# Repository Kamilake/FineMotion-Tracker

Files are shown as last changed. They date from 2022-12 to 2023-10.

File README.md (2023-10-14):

FineMotionLogo8bit

# SlimeVR Based Full-Body Tracker

```
혹시 트래커를 어디선가 구해서 QR코드를 스캔해 여기에 왔고 구매자가 아무것도 알려주지 않았다면 디스코드 kamilake 로 디엠주세요!
```

ESP8266 Motion Capture Devices for SlimeVR Ecosystem

Thinnest SlimeVR Tracker!

Full SMT PCB operating in MPU-6500 6DoF mode

Operate with all 5V chargers, including C to C PD chargers.

You can use it simply by ordering it from the fabricator


<!--![FBT_Round_2022-Feb-21_12-32-22AM-000_CustomizedView14755583882_png - 복사본](https://user-images.githubusercontent.com/15166740/161261406-e853b4be-313f-4721-82e6-cb6b48a9e55c.png)
![KakaoTalk_20220223_222725417_01](https://user-images.githubusercontent.com/15166740/161364606-c8e09892-575d-4725-931e-a6b7f6b5f61f.jpg)
![KakaoTalk_20220223_222725417](https://user-images.githubusercontent.com/15166740/161364617-89621510-34f0-4919-be8a-b33350d9140c.jpg)
![image](https://user-images.githubusercontent.com/15166740/161454675-0740d4ca-4264-4b6e-8f56-9f29aa31817a.png)
![image](https://user-images.githubusercontent.com/15166740/161454916-a54c4693-e9c1-454c-85dc-dd0a7822720e.png)
![KakaoTalk_20220420_084354356_01](https://user-images.githubusercontent.com/15166740/164119670-261c3e02-e0fe-4508-9886-2ccc19d5d1fd.jpg)
![KakaoTalk_20220726_093847052](https://user-images.githubusercontent.com/15166740/180898132-acec5d8d-918e-4d9e-ad32-58ac35cc4740.png)-->




KakaoTalk_20221224_130624400_03
KakaoTalk_20221224_130624400_07

## Why should that tracker be able to be detached from the strap?

It is because of the start-up calibration of the MPU-6000 series.

When the MPU first powers up, the DMP measures the static noise, but this needs to be done on every boot. In other words, to reboot the tracker in-game, you must detach it from your body. Not only does this strap adapter help make it very convenient, but it is also a great help in tracker maintenance!

It only takes 10 seconds for you to assemble the tracker sensor and adapter, and less than 30 seconds to assemble all the trackers to your body \:P

It is eco-friendly to save the life of Velcro straps and easily replace broken adapters.

## Specification

- Power Rating: 500mA@5V (TProg: 2.4KOhm)
- Wi-Fi: 802.11bgn 2.4GHz (20.5mW@2dBi)
- Protection Circuit: Depend on battery
- IMU: Invensense MPU-6500 6DoF Attitude detection sensor
- The radio wave safety of this product has been verified by a nationally recognized testing agency.

## Prerequirements

- PCB: [This Repo!](/PCBs)
- 3D Model: [This Repo!](/3D%20Models)
- Belt Strap: https://aliexpress.com/item/1005003002833146.html, or any 50mm width Strap
- Battery: https://aliexpress.com/item/1005004165245143.html, or any 702050 Cell
- USB Cable: https://aliexpress.com/item/1005004409330904.html, or any Type-C cables

## How do I make it?

1. [Order PCB!](/PCBs)
2. Order Belt, Battery!
3. [Print Shell!](/3D%20Models)
4. Go to SteamVR...

## defines.h
```cpp
#define FineMotion_v5
#define IMU IMU_MPU6500
#define IMU_ROTATION DEG_0
#define BOARD BOARD_NODEMCU
#define SECOND_IMU IMU
#define SECOND_IMU_ROTATION IMU_ROTATION
#define BATTERY_MONITOR 1
#define BATTERY_SHIELD_RESISTANCE 0
#define BATTERY_SHIELD_R1 12
#define BATTERY_SHIELD_R2 47
#define PIN_IMU_SDA 4
#define PIN_IMU_SCL 5
#define PIN_IMU_INT 0xFF
#define PIN_IMU_INT_2 0xFF
#define PIN_BATTERY_LEVEL 17
```

## Why do trackers have to be thin?





The thinner the tracker, the closer the IMU is to the bone and the better the tracking accuracy. It is less affected by inertial force in fast movements.. Above all, it is comfortable when lying on the bed facing the tracker!

## License
**This hardware is licensed under the CERN-OHL-P v2 license**, which is a permissive,
non-viral and non-reciprocal open hardware license. Unlike software licenses like
MIT and Apache 2.0, it better handles the nuances of hardware and protects both
the licensor and licensee from patent lawsuits.

**Unless you explicitly state otherwise, any contribution intentionally submitted
for inclusion in this work by you, shall be licensed as above, without any
additional terms or conditions.**

### Conveying notice of License
Note that as part of the CERN-OHL-P v2 license, recipients of manufactured
hardware must also receive notice of the above license. One such
method of conveying the notice is to include a link to the original source repo,
or printing "Licensed under CERN-OHL-P v2" on the PCB silkscreen. For more info,
see [here](https://ohwr.org/project/cernohl/wikis/Documents/CERN-OHL-version-2).

This is conceptually similar to the MIT/Apache 2.0 Licenses, where the original
license must still be included as a notice even when the source is modified and
subsequently relicensed under different terms.

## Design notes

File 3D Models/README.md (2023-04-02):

# File List

- FineMotion Tracker v172.f3z

  Fusion 360 archive file for who want to edit this model

- FineMotion Tracker v172.step

  STEP file for who want to import this model to other software

- FineMotion Tracker v172.usdc

  USD file for who want to import this model to other software

- FineMotion Tracker v172_AUX Sensor_1_AUX Cover.3mf

  3MF file for 3D printing
  
  Wired External Sensor Cover (Duplicate of Main Sensor Cover)

- FineMotion Tracker v172_AUX Sensor_1_AUX Shell.3mf

  3MF file for 3D printing
  
  Wired External Sensor Shell (Duplicate of Main Sensor Shell)

- FineMotion Tracker v172_AUX Sensor_1_FineMotion AUX Sensor PCB.3mf

  3MF file for Rendering (Do not print)
  
  Wired External Sensor PCB

- FineMotion Tracker v172_Curved Strap Mount with Supporter_1_Curved Strap Mount with Supporter.3mf

  3MF file for 3D printing
  
  Curved Strap Mount with Supporter (Vertical Printing) (Recommended)

- FineMotion Tracker v172_Curved Strap Mount_1_Curved Strap Mount.3mf

  3MF file for 3D printing
  
  Curved Strap Mount

- FineMotion Tracker v172_FineMotion_1_BNO085 Cover_1_BNO085 Cover.3mf

  3MF file for 3D printing
  
  Adafruit BNO085 Sensor Cover for Main Sensor (Usually not needed)

- FineMotion Tracker v172_FineMotion_1_Battery_1_Battery.3mf

  3MF file for Rendering (Do not print)
  
  702050 Lipo Battery 3D Model

- FineMotion Tracker v172_FineMotion_1_Chassis_1_Chassis.3mf

  3MF file for 3D printing
  
  Main Sensor Chassis (Recommended)

- FineMotion Tracker v172_FineMotion_1_Main Cover_1_Main Cover.3mf

  3MF file for 3D printing
  
  Main Sensor / External Sensor Cover (Recommended)

- FineMotion Tracker v172_FineMotion_1_PCB_1_FineMotion v5a PCB.3mf

  3MF file for Rendering (Do not print)
  
  Main Sensor PCB

- FineMotion Tracker v172_Flat Strap Mount (Easy Charge)_1_Flat Strap Mount (Easy Charge).3mf

  3MF file for 3D printing
  
  Flat Strap Mount (Not recommended)

- FineMotion Tracker v172_Flat Strap Mount_1_Flat Strap Mount.3mf

  3MF file for 3D printing
  
  Flat Strap Mount (Chest/Waist Mount) (Recommended)

## [For F360 user] What is \*.f3z?



As you can see in the screenshot, that's it.

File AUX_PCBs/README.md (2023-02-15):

# Custom assembly using Kikit JLC

Due to JLCPCB's new assembly policy, soldering on the bottom side or using a non-black PCB will incur additional charges.
Bottom side soldering is not possible if the "Economic" assembly option is selected.
As the bottom side soldering is only for the connector, manual assembly is recommended.  
But.. if you ordering more than 31 boards, it is more economical to choose the `Standard assembly` option with panelization.  
If you have any further questions, please feel free to contact me!(Issues, mail, Discord, etc.)  

- You need `KiCad 6.0 Command Prompt` and [Kikit](https://github.com/yaqwsx/KiKit) with KiCad 6

## Panalize and Fabrication

```batch
kikit panelize ^
    -p :jlcTooling ^
    --layout "grid; rows: 7; cols: 3; space: 3mm" ^
    --tabs "fixed; hwidth: 10mm; vwidth: 15mm" ^
    --cuts vcuts ^
    --source "tolerance: 1000mm" ^
    --framing "tightframe; width: 5mm; space: 3mm; " ^
    --post "millradius: 1mm" ^
    "./FineMotion_AUX.kicad_pcb" ^
    "FineMotion_AUX_panel.kicad_pcb"

kikit fab jlcpcb ^
    --assembly ^
    --schematic ./FineMotion_AUX.kicad_sch ^
    --ignore TP1,J1 ^
    "./FineMotion_AUX_panel.kicad_pcb" ^
    "./Gerber/FineMotion_Panel"

```

## Fabrication Only

### Using Default Configuration

```batch
kikit fab jlcpcb ^
    --assembly ^
    --schematic ./FineMotion_AUX.kicad_sch ^
    --ignore TP1,TP2 ^
    --no-drc ^
    "./FineMotion_AUX_panel.kicad_pcb" ^
    "./Gerber/FineMotion"
```

<br><hr><br>

## Panalize and Fabrication Extension Sensor

```batch
```

## Fabrication Extension Sensor Only

### Using Default Configuration

```batch
```

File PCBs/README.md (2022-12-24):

# Custom assembly using Kikit JLC

Due to JLCPCB's new assembly policy, soldering on the bottom side or using a non-black PCB will incur additional charges.   
Bottom side soldering is not possible if the "Economic" assembly option is selected.   
As the bottom side soldering is only for the connector, manual assembly is recommended.  
But.. if you ordering more than 31 boards, it is more economical to choose the `Standard assembly` option with panelization.  
If you have any further questions, please feel free to contact me!(Issues, mail, Discord, etc.)  

- You need `KiCad 6.0 Command Prompt` and [Kikit](https://github.com/yaqwsx/KiKit) with KiCad 6

## Panalize and Fabrication
```batch
kikit panelize ^
    -p :jlcTooling ^
    --layout "grid; rows: 7; cols: 3; space: 3mm" ^
    --tabs "fixed; hwidth: 10mm; vwidth: 15mm" ^
    --cuts vcuts ^
    --source "tolerance: 1000mm" ^
    --post "millradius: 1mm" ^
    "./FineMotion-5.kicad_pcb" ^
    "FineMotion-5_panel.kicad_pcb"

kikit fab jlcpcb ^
    --assembly ^
    --schematic ./FineMotion-5.kicad_sch ^
    --ignore TP1,TP2 ^
    --no-drc ^
    "./FineMotion-5_panel.kicad_pcb" ^
    "./Gerber/FineMotion_Panel"
```

## Fabrication Only

### Using Default Configuration
```batch
kikit fab jlcpcb ^
    --assembly ^
    --schematic ./FineMotion-5.kicad_sch ^
    --ignore TP1,TP2 ^
    --no-drc ^
    "./FineMotion-5_panel.kicad_pcb" ^
    "./Gerber/FineMotion"
```

<br><hr><br>   

## Panalize and Fabrication Extension Sensor
```batch
```

## Fabrication Extension Sensor Only

### Using Default Configuration
```batch
```
<!--
### Using internal MPU-6050+QMC5883L and Left side Lipo
```batch
kikit fab jlcpcb ^
    --assembly ^
    --schematic ./KTracker.kicad_sch ^
    --ignore BT1,J1,J4,J5 ^
    --no-drc ./KTracker.kicad_pcb ^
    "./Gerber/Using internal MPU-6050+QMC5883L and Left side Lipo"
```

### Using GY-521 and bottom Lipo
```batch
kikit fab jlcpcb ^
    --assembly ^
    --schematic ./KTracker.kicad_sch ^
    --ignore U8,U3,R20,R21,C16,C12,C11,R12,R11,BT1,J3,J4,J5 ^
    --no-drc ./KTracker.kicad_pcb ^
    "./Gerber/Using GY-521 and bottom Lipo"

```

### Using GY-521 and 18650
```batch
kikit fab jlcpcb ^
    --assembly ^
    --schematic ./KTracker.kicad_sch ^
    --ignore U8,U3,R20,R21,C16,C12,C11,R12,R11,J1,J3,J4,J5 ^
    --no-drc ./KTracker.kicad_pcb ^
    "./Gerber/Using GY-521 and 18650"

```

kikit fab jlcpcb --assembly --schematic ./FineMotion-5.kicad_sch --ignore TP1,TP2 --no-drc ./FineMotion-5.kicad_pcb "./Gerber/FM6500"

kikit fab jlcpcb --assembly --schematic ./KTracker_AUX.kicad_sch  --ignore A1 --no-drc ./KTracker_AUX.kicad_pcb "./Gerber/FM6500E"

kikit panelize ^
    -p :jlcTooling ^
    --layout "grid; rows: 7; cols: 3; space: 3mm" ^
    --tabs "fixed; hwidth: 10mm; vwidth: 15mm" ^
    --cuts vcuts ^
    --source "tolerance: 1000mm" ^
    --post "millradius: 1mm" ^
    "./FineMotion-5.kicad_pcb" ^
    "FineMotion-5_panel.kicad_pcb"

kikit fab jlcpcb ^
    --assembly ^
    --schematic ./FineMotion-5.kicad_sch ^
    --ignore TP1,TP2 ^
    --no-drc ^
    "./FineMotion-5_panel.kicad_pcb" ^
    "./Gerber/FineMotion_Panel"

---

-->

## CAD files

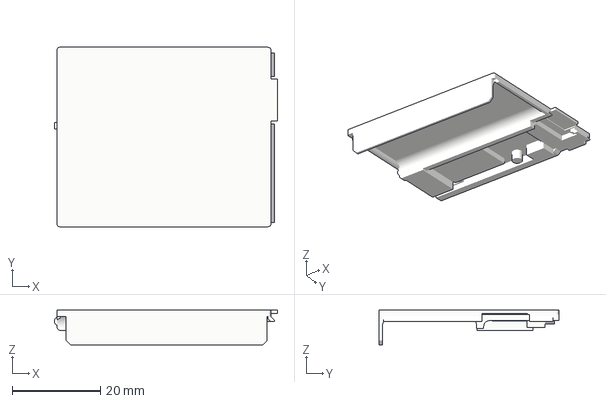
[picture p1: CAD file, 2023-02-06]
3D Models/FineMotion Tracker v172_FineMotion_1_Main Cover_1_Main Cover.3mf
50.4 x 40.6 x 7.90 mm

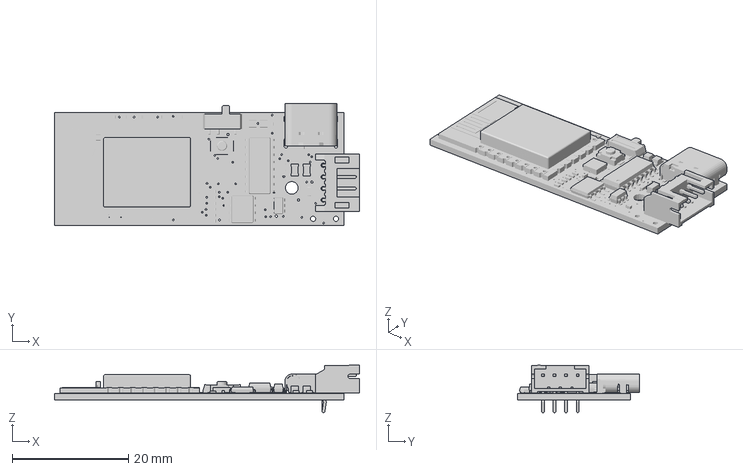
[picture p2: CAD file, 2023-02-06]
3D Models/FineMotion Tracker v172_FineMotion_1_PCB_1_FineMotion v5a PCB.3mf
52.6 x 21.0 x 8.25 mm

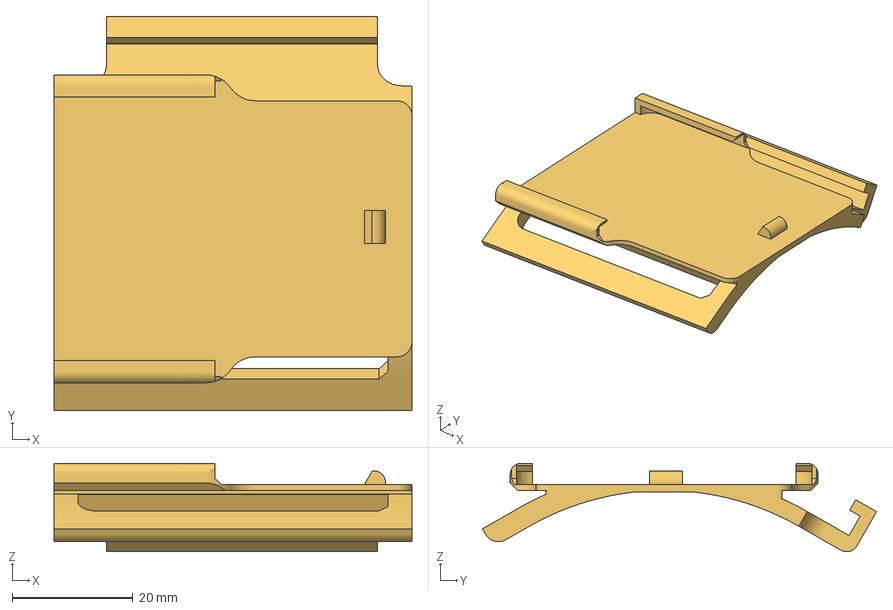
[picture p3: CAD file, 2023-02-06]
3D Models/FineMotion Tracker v172_Curved Strap Mount_1_Curved Strap Mount.3mf
59.4 x 65.4 x 14.7 mm

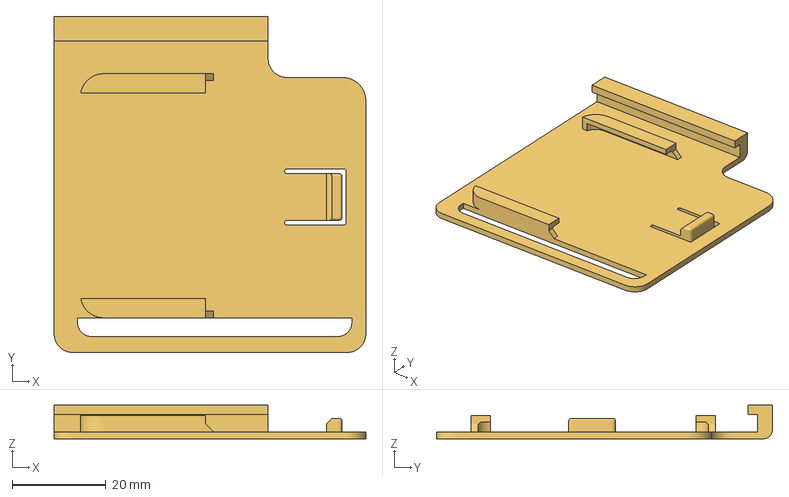
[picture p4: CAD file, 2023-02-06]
3D Models/FineMotion Tracker v172_Flat Strap Mount (Easy Charge)_1_Flat Strap Mount (Easy Charge).3mf
66.5 x 71.7 x 7.20 mm

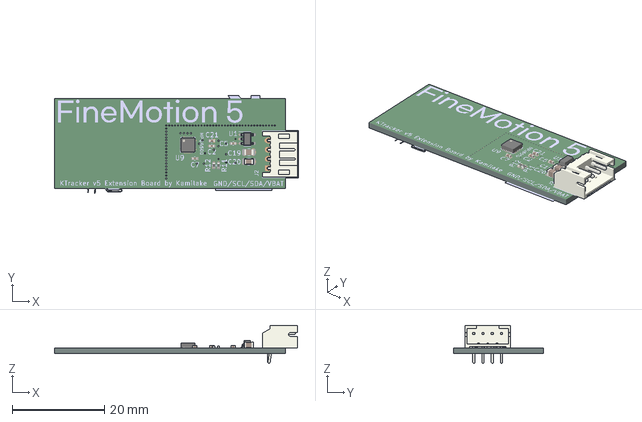
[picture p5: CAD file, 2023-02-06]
3D Models/FineMotion Tracker v172_AUX Sensor_1_FineMotion AUX Sensor PCB.3mf
52.8 x 21.2 x 8.25 mm

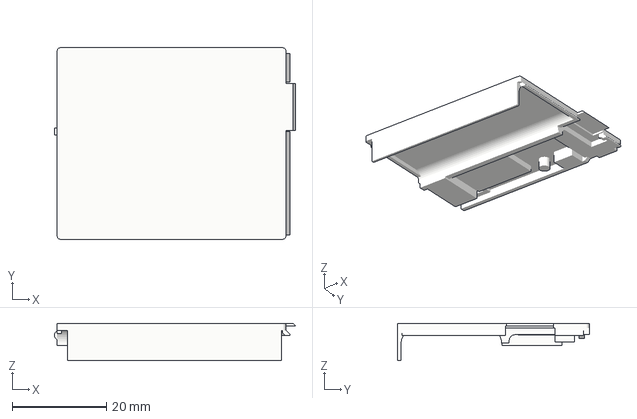
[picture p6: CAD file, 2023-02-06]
3D Models/FineMotion Tracker v172_AUX Sensor_1_AUX Cover.3mf
51.1 x 40.6 x 7.90 mm

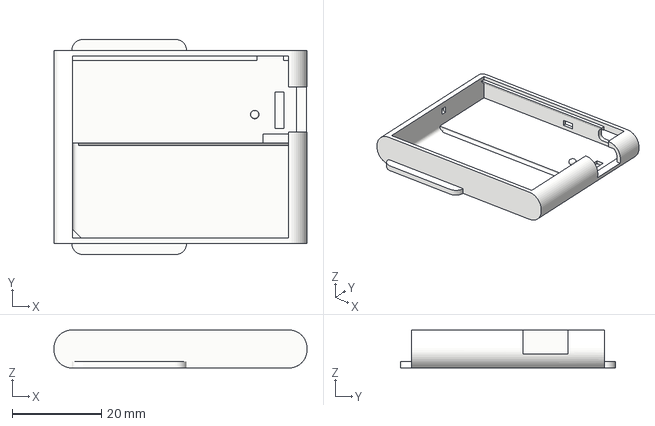
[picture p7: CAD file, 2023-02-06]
3D Models/FineMotion Tracker v172_FineMotion_1_Chassis_1_Chassis.3mf
56.7 x 48.2 x 8.50 mm

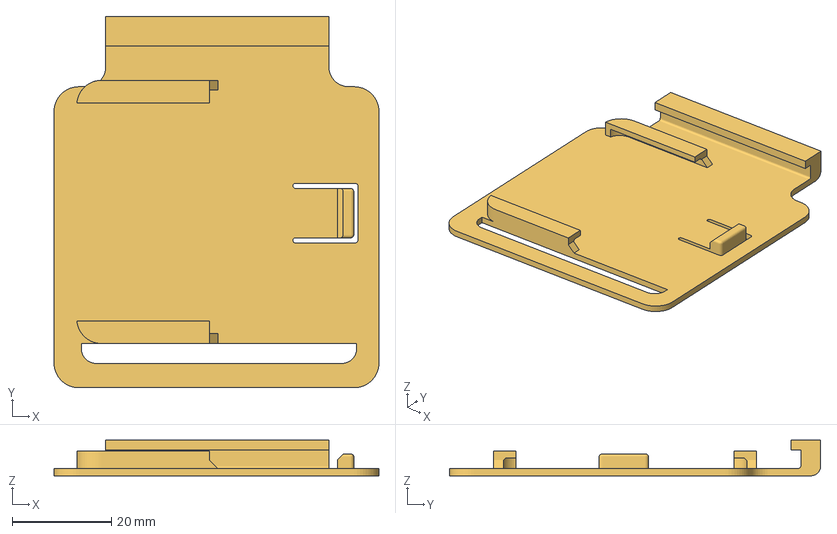
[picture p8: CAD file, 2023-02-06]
3D Models/FineMotion Tracker v172_Flat Strap Mount_1_Flat Strap Mount.3mf
65.5 x 74.9 x 7.20 mm

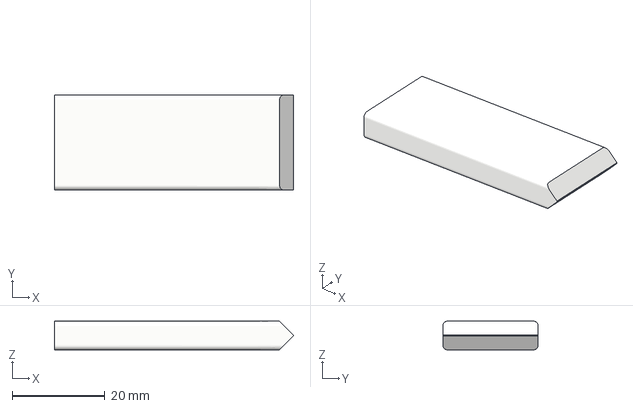
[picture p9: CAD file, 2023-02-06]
3D Models/FineMotion Tracker v172_FineMotion_1_Battery_1_Battery.3mf
51.5 x 20.5 x 6.20 mm

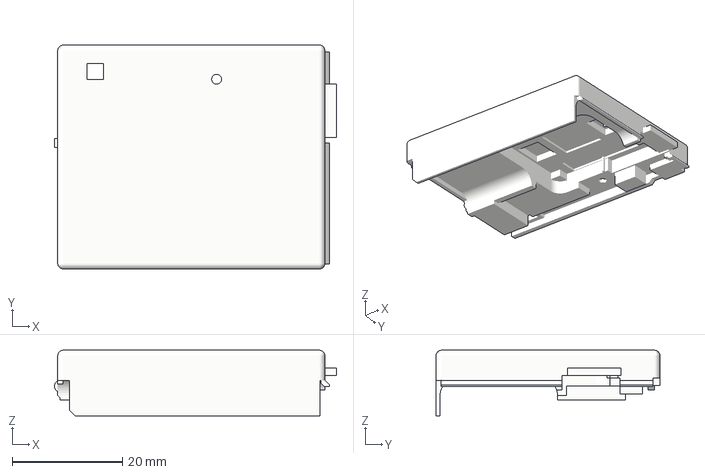
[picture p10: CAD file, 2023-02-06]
3D Models/FineMotion Tracker v172_FineMotion_1_BNO085 Cover_1_BNO085 Cover.3mf
51.1 x 40.6 x 11.9 mm

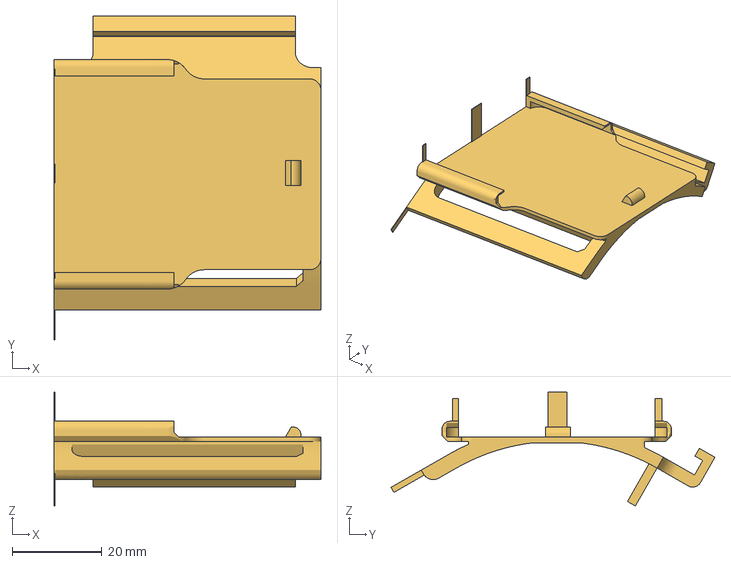
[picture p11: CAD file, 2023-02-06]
3D Models/FineMotion Tracker v172_Curved Strap Mount with Supporter_1_Curved Strap Mount with Supporter.3mf
59.4 x 72.1 x 25.4 mm

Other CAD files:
3D Models/FineMotion Tracker v172_500원 동전.3mf
3D Models/FineMotion Tracker v172_AUX Sensor_1_AUX Shell.3mf

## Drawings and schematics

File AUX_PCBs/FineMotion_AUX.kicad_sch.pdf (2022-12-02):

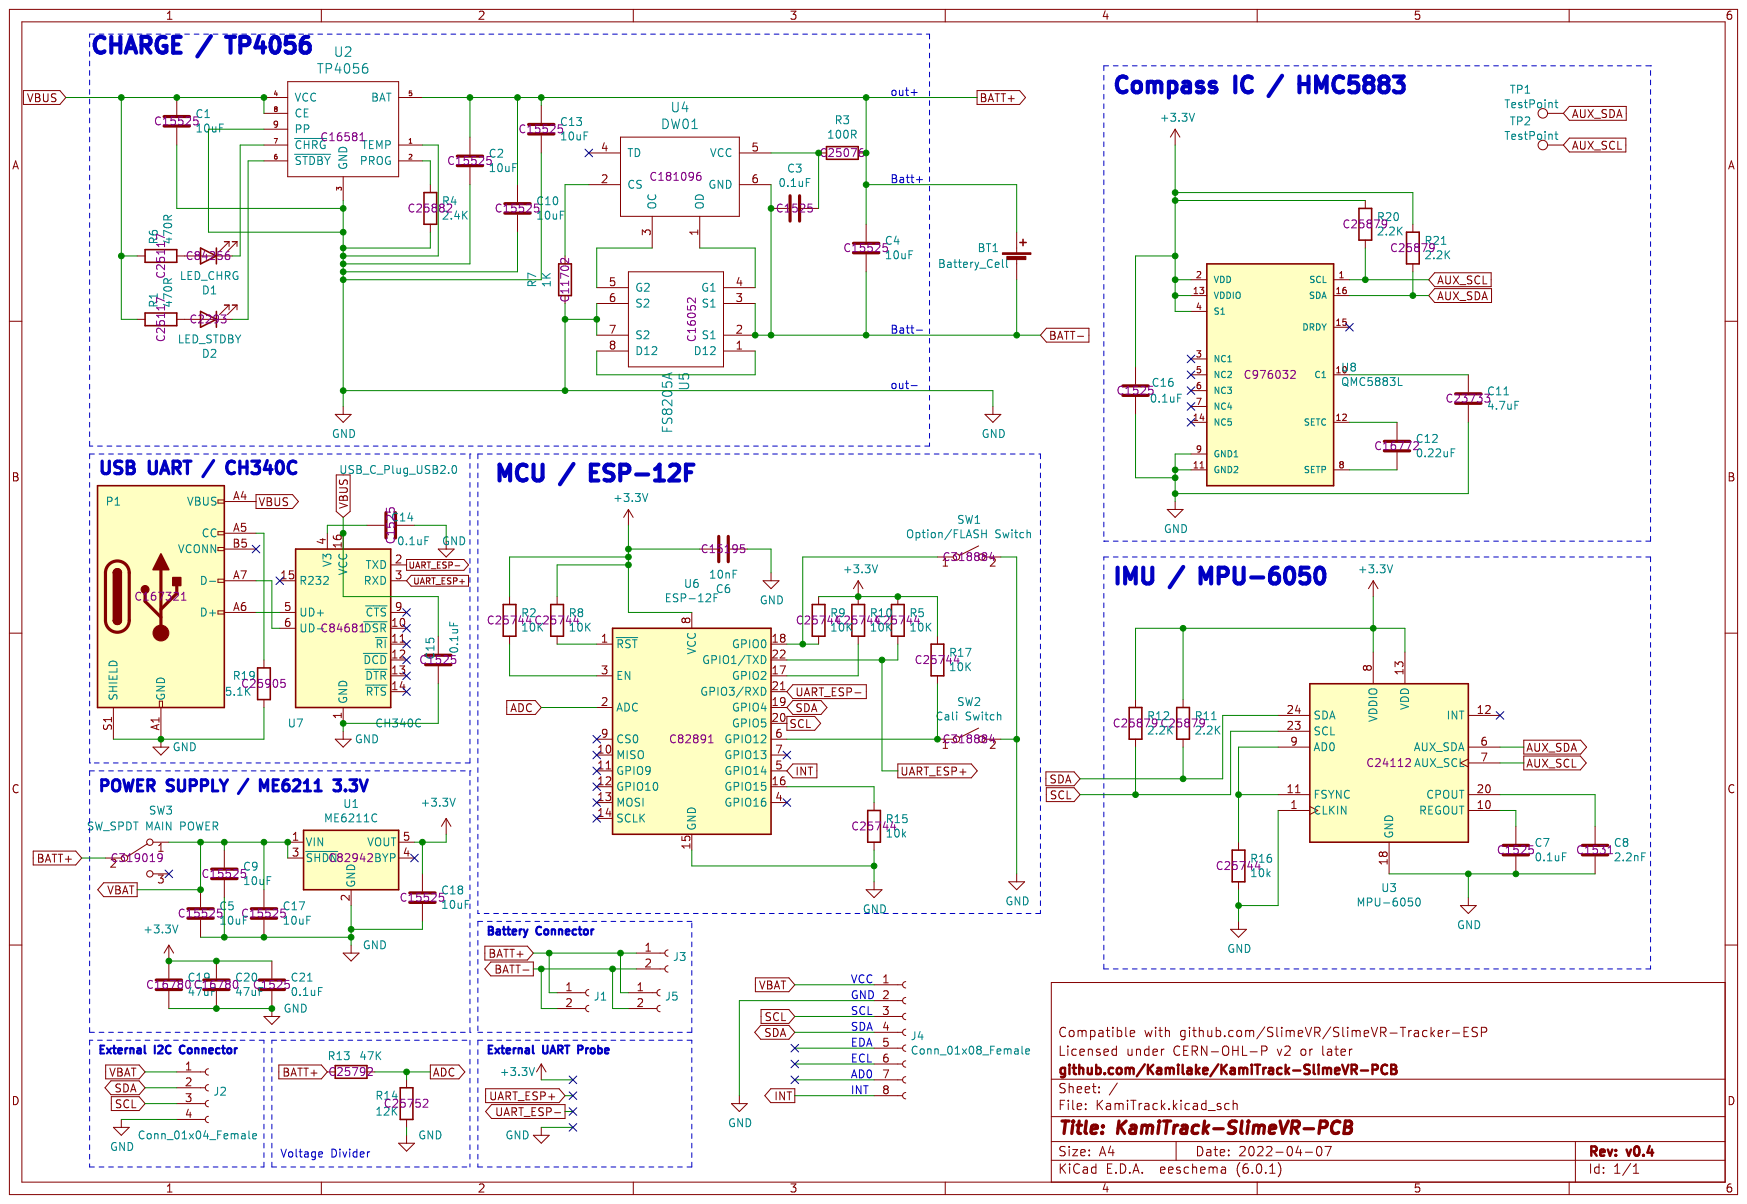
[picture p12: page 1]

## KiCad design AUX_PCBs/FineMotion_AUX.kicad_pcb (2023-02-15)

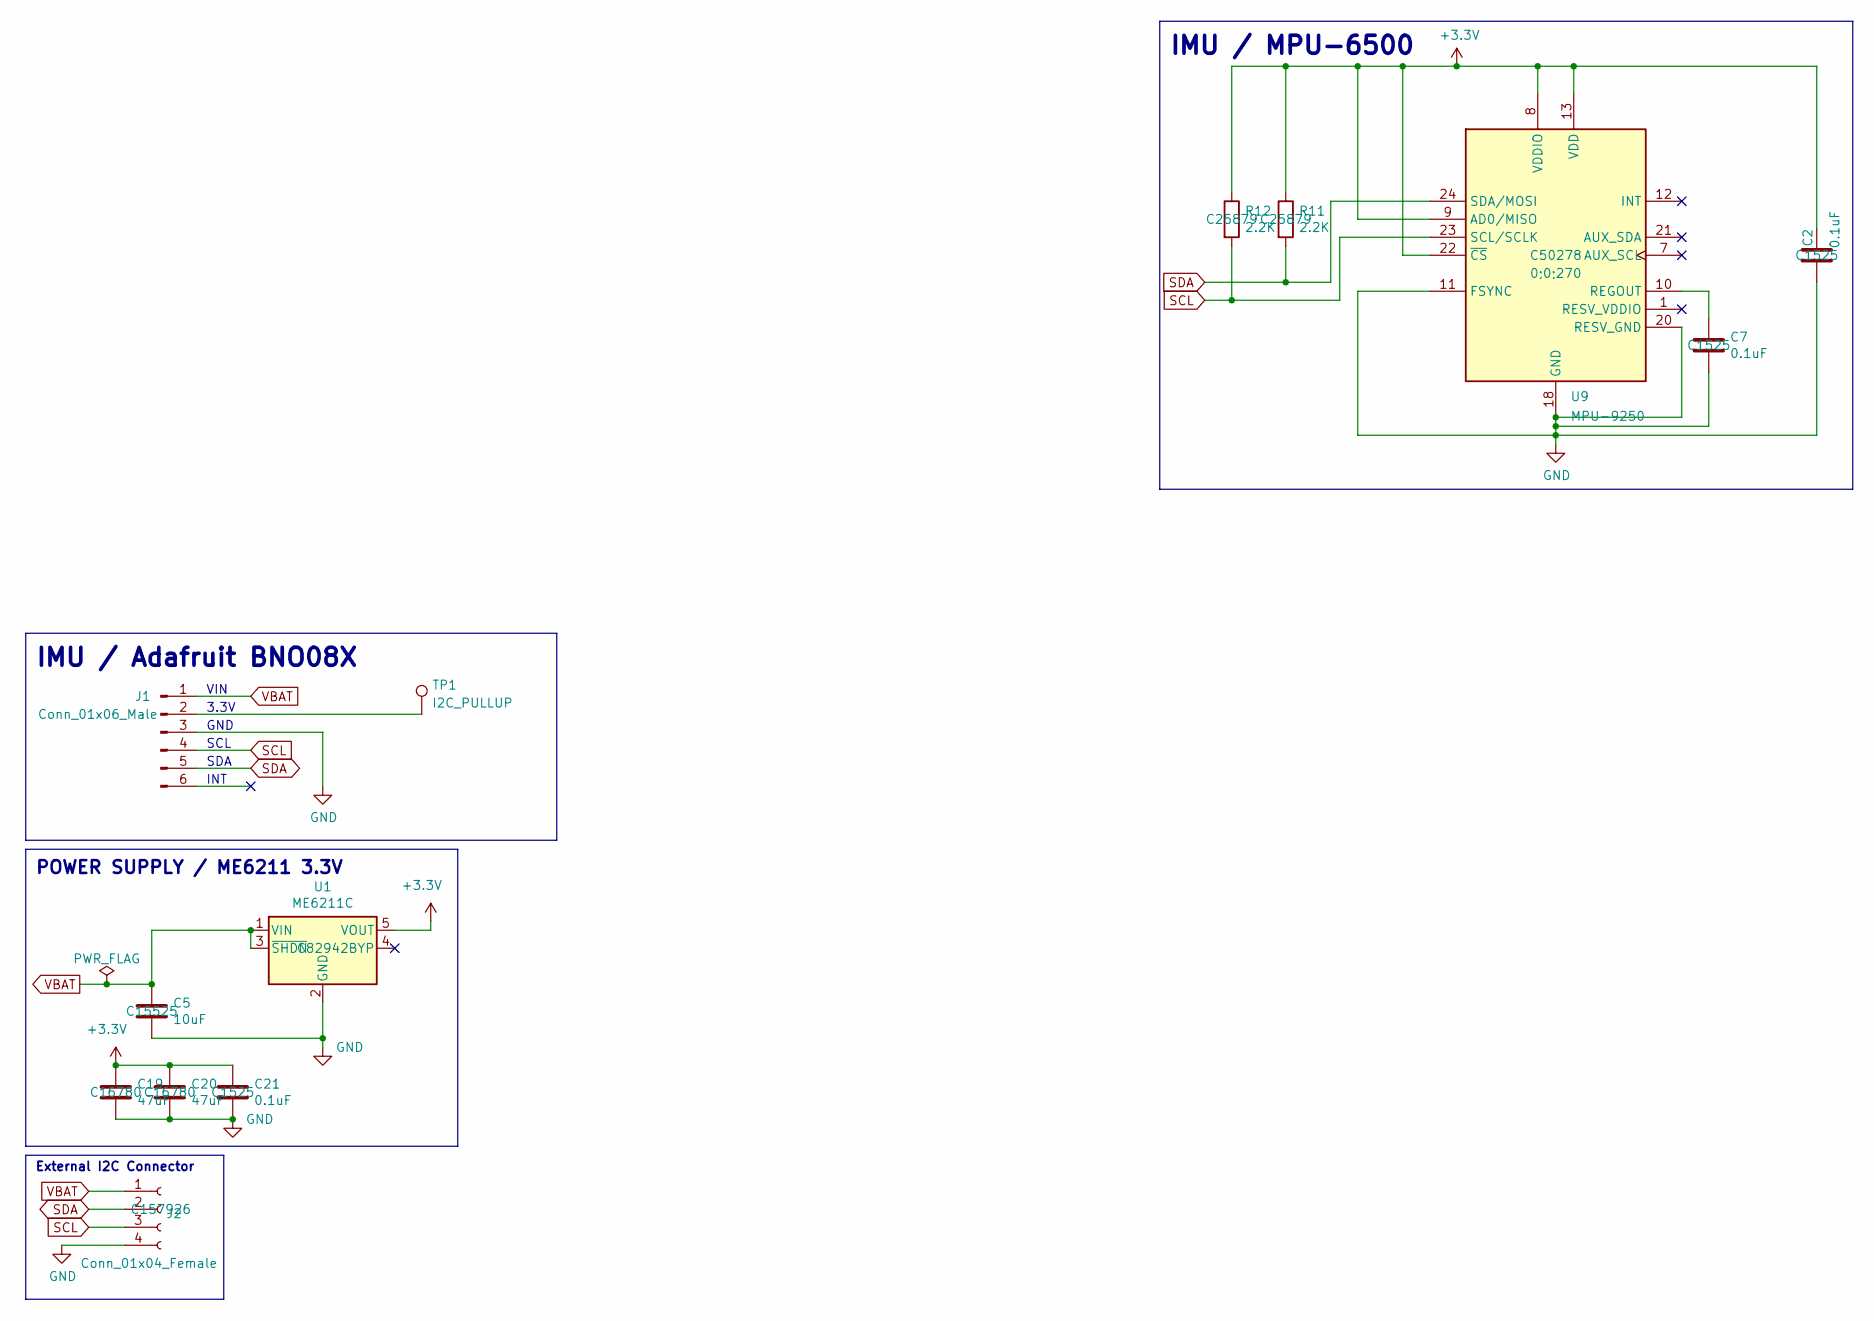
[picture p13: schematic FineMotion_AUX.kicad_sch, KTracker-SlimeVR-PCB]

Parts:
C2, C7, C21: 0.1uF; C_0402_1005Metric; LCSC C1525
C5: 10uF; C_0402_1005Metric; LCSC C15525
C19, C20: 47uF; C_0805_2012Metric; LCSC C16780
J1: Conn_01x06_Male; PinHeader_1x06_P2.54mm_Vertical
J2: Conn_01x04_Female; JST_PH_S4B-PH-K_1x04_P2.00mm_Horizontal; LCSC C157926
R11, R12: 2.2K; R_0402_1005Metric; LCSC C25879
TP1: I2C_PULLUP; TestPoint_Pad_D1.5mm
U1: ME6211C; SOT-23-5; LCSC C82942
U9: MPU-9250; InvenSense_QFN-24_3x3mm_P0.4mm; LCSC C50278

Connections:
+3V3: C2.2, C19.1, C20.1, C21.1, R11.1, R12.1, U1.5 (VOUT), U9.8 (VDDIO), U9.9 (AD0/MISO), U9.13 (VDD), U9.22 (~CS)
GND: C2.1, C5.2, C7.2, C19.2, C20.2, C21.2, J1.3, J2.4, U1.2 (GND), U9.11 (FSYNC), U9.18 (GND), U9.20 (RESV_GND)
unnamed: C7.1, U9.10 (REGOUT)
unnamed: J1.2, TP1.1
SCL: J1.4, J2.3, R12.2, U9.23 (SCL/SCLK)
SDA: J1.5, J2.2, R11.2, U9.24 (SDA/MOSI)
VBAT: C5.1, J1.1, J2.1, U1.1 (VIN), U1.3 (~SHDN)

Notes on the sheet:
External I2C Connector
SCL
IMU / MPU-6500
SDA
IMU / Adafruit BNO08X
POWER SUPPLY / ME6211 3.3V
GND
VIN
INT
3.3V

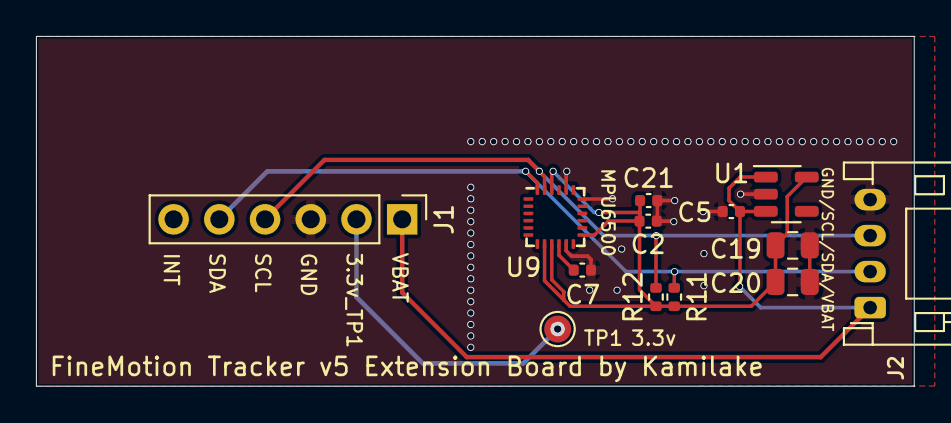
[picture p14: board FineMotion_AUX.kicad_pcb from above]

Board: 2 copper layers, 48.8 x 19.4 mm, 13 parts (0 on the bottom side), 7 nets.

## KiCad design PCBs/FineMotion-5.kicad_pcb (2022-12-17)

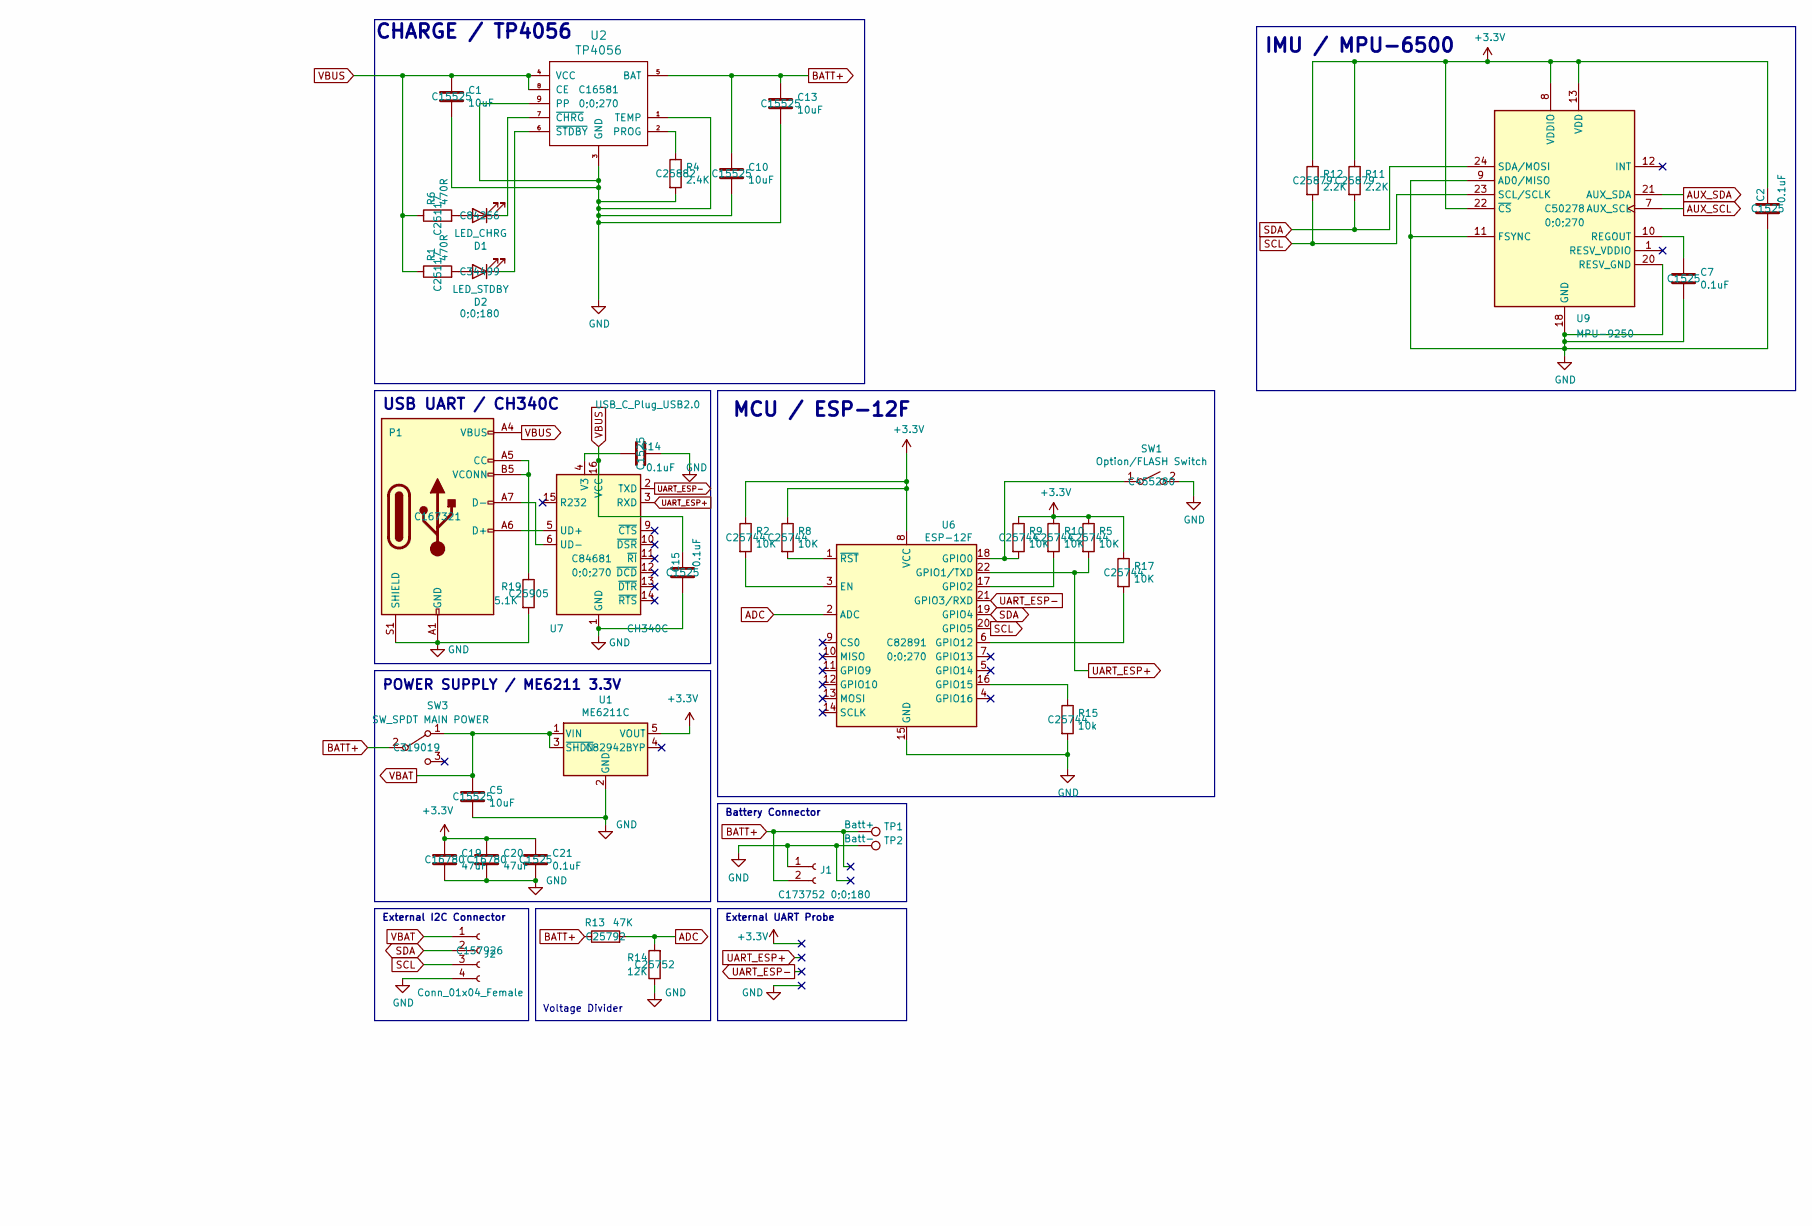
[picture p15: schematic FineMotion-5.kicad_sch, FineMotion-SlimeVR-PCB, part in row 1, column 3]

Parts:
C1, C5, C10, C13: 10uF; C_0402_1005Metric; LCSC C15525
C2, C7, C14, C15, C21: 0.1uF; C_0402_1005Metric; LCSC C1525
C19, C20: 47uF; C_0805_2012Metric; LCSC C16780
D1: LED_CHRG; LED_0805_2012Metric; LCSC C84256
D2: LED_STDBY; LED_0805_2012Metric; LCSC C34499
J1: Conn_01x02_Female; JST_PH_S2B-PH-K_1x02_P2.00mm_Horizontal; LCSC C173752
J2: Conn_01x04_Female; JST_PH_S4B-PH-K_1x04_P2.00mm_Horizontal; LCSC C157926
P1: USB_C_Plug_USB2.0; USB_C_Receptacle_HRO_TYPE-C-31-M-12; LCSC C167321
R1, R6: 470R; R_0402_1005Metric; LCSC C25117
R2, R5, R8, R9, R10, R17: 10K; R_0402_1005Metric; LCSC C25744
R4: 2.4K; R_0402_1005Metric; LCSC C25882
R11, R12: 2.2K; R_0402_1005Metric; LCSC C25879
R13: 47K; R_0402_1005Metric; LCSC C25792
R14: 12K; R_0402_1005Metric; LCSC C25752
R15: 10k; R_0402_1005Metric; LCSC C25744
R19: 5.1K; R_0402_1005Metric; LCSC C25905
SW1: Option/FLASH Switch; TS-1088R; LCSC C455280
SW3: SW_SPDT MAIN POWER; SW_SPDT_PCM12; LCSC C319019
TP1: Batt+; Pin_D0.9mm_L10.0mm_W2.4mm_FlatFork
TP2: Batt-; Pin_D0.9mm_L10.0mm_W2.4mm_FlatFork
U1: ME6211C; SOT-23-5; LCSC C82942
U2: TP4056; HSOP-8-1EP_3.9x4.9mm_P1.27mm_EP2.41x3.1mm_ThermalVias; LCSC C16581
U6: ESP-12F; ESP-12E; LCSC C82891
U7: CH340C; SOIC-16_3.9x9.9mm_P1.27mm; LCSC C84681
U9: MPU-9250; InvenSense_QFN-24_3x3mm_P0.4mm; LCSC C50278

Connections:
+3V3: C2.2, C19.1, C20.1, C21.1, R2.1, R5.1, R8.1, R9.1, R10.1, R11.1, R12.1, R17.1, U1.5 (VOUT), U6.8 (VCC), U9.8 (VDDIO), U9.13 (VDD), U9.22 (~CS)
ADC: R13.2, R14.2, U6.2 (ADC)
AUX_SCL: U9.7 (AUX_SCL)
AUX_SDA: U9.21 (AUX_SDA)
BATT+: C10.1, C13.1, J1.2, R13.1, SW3.2 (B), TP1.1, U2.5 (BAT)
GND: C1.2, C2.1, C5.2, C7.2, C10.2, C13.2, C14.2, C15.1, C19.2, C20.2, C21.2, J1.1, J2.4, P1.A1 (GND), P1.A12 (GND), P1.B1 (GND), P1.B12 (GND), P1.S1 (SHIELD), R4.2, R14.1, R15.2, R19.2, SW1.2 (B), TP2.1, U1.2 (GND), U2.1 (TEMP), U2.3 (GND), U2.9 (PP), U6.15 (GND), U7.1 (GND), U9.9 (AD0/MISO), U9.11 (FSYNC), U9.18 (GND), U9.20 (RESV_GND)
unnamed: C7.1, U9.10 (REGOUT)
unnamed: C14.1, U7.4 (V3)
unnamed: D1.1 (K), U2.7 (~CHRG)
unnamed: D1.2 (A), R6.2
unnamed: D2.1 (K), U2.6 (~STDBY)
unnamed: D2.2 (A), R1.2
unnamed: P1.A5 (CC), P1.B5 (VCONN), R19.1
unnamed: P1.A6 (D+), U7.5 (UD+)
unnamed: P1.A7 (D-), U7.6 (UD-)
unnamed: R2.2, U6.3 (EN)
unnamed: R4.1, U2.2 (PROG)
unnamed: R8.2, U6.1 (~RST)
unnamed: R9.2, SW1.1 (A), U6.18 (GPIO0)
unnamed: R10.2, U6.17 (GPIO2)
unnamed: R15.1, U6.16 (GPIO15)
unnamed: R17.2, U6.6 (GPIO12)
SCL: J2.3, R12.2, U6.20 (GPIO5), U9.23 (SCL/SCLK)
SDA: J2.2, R11.2, U6.19 (GPIO4), U9.24 (SDA/MOSI)
UART_ESP+: R5.2, U6.22 (GPIO1/TXD), U7.3 (RXD)
UART_ESP-: U6.21 (GPIO3/RXD), U7.2 (TXD)
VBAT: C5.1, J2.1, SW3.1 (A), U1.1 (VIN), U1.3 (~SHDN)
VBUS: C1.1, C15.2, P1.A4 (VBUS), P1.A9 (VBUS), P1.B4 (VBUS), P1.B9 (VBUS), R1.1, R6.1, U2.4 (VCC), U2.8 (CE), U7.16 (VCC)

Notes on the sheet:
Voltage Divider
External UART Probe
MCU / ESP-12F
External I2C Connector
IMU / MPU-6500
POWER SUPPLY / ME6211 3.3V
CHARGE / TP4056
USB UART / CH340C
Battery Connector

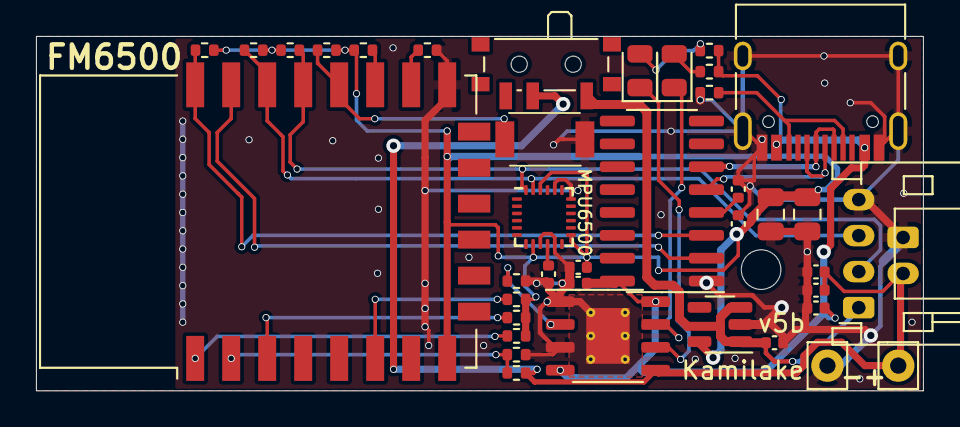
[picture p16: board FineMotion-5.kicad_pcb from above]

Board: 2 copper layers, 49.3 x 19.7 mm, 40 parts (1 on the bottom side), 26 nets.

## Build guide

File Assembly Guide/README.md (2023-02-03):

# Assembly Guide

I will be uploading assembly and programming guides here!

But right now no one is interested in the project so there is no guide, 
let me know if you are interested! I will write that!

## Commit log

2022-12-17 Update PCB Remark
    [FineMotion-5.kicad_pcb, FineMotion-5.kicad_sch]
2023-02-01 renamed: KTracker_Extension v5a.wrl -> FimeMotion AUX Sensor PCB 3D Model v5a.wrl
2023-02-01 renamed: AUX_PCBs/KTracker_AUX.kicad_pcb -> AUX_PCBs/FineMotion_AUX.kicad_pcb
    [FineMotion_AUX.kicad_pcb, FineMotion_AUX.kicad_sch]
2023-02-01 Update 3D Model to v172
    [FineMotion Tracker v172_FineMotion Tracker v172_AUX Sensor_1_AUX Cover.3mf, FineMotion Tracker v172_FineMotion Tracker v172_AUX Sensor_1_AUX Shell.3mf, FineMot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]
2023-02-06 Fix incorrect objects
    [FineMotion Tracker v172_500원 동전.3mf, FineMotion Tracker v172_AUX Sensor_1_AUX Cover.3mf, FineMotion Tracker v172_AUX Sensor_1_AUX Shell.3mf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]
2023-02-08 Placement of pads to assemble the BNO085 module
    [FineMotion_AUX.kicad_pcb, FineMotion_AUX.kicad_sch]
2023-02-08 Premium logo~
    [FineMotion_AUX.kicad_pcb]
2023-02-15 Update manufacturing date
    [FineMotion_AUX.kicad_pcb]

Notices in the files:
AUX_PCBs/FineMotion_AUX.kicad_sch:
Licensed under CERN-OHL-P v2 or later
